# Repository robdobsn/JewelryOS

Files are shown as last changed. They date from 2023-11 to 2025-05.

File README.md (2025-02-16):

# JewelOS - Minimal OS for Jewelry

ESP32-C3 based minimal OS for Jewelry.

To build install the Raft CLI (https://github.com/robdobsn/RaftCLI)

Then run:

raft run -p <SERIALPORT>

## Devices Log

| Date | Serial | PCB Version | Notes |
|---|---|---|---|
| 2025-02-15 | 0103 | V1.5 | Seems to allow power off without any mods? BLE performance is poor. |
| 2025-02-15 | 0104 | V1.5 | Modified to remove Q4 and D5 with a wire between CHG_IN and VBAT. Turns off ok but needs power button held down to program. |

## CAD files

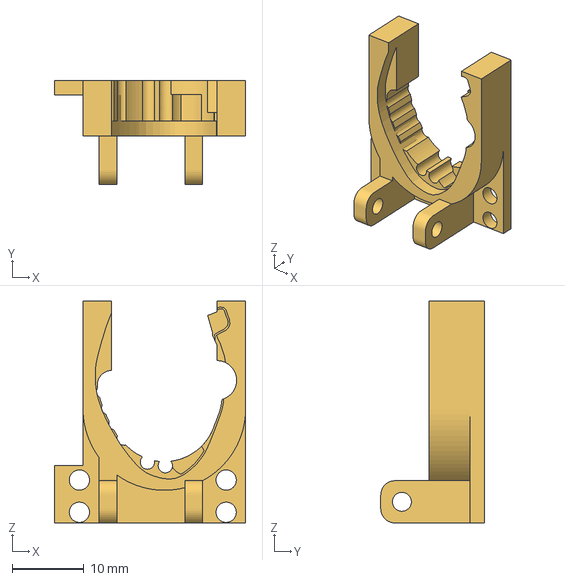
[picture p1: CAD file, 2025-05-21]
hardware/Heart Earrings/Clip1.5/Clip Base.3mf
26.7 x 14.5 x 31.0 mm

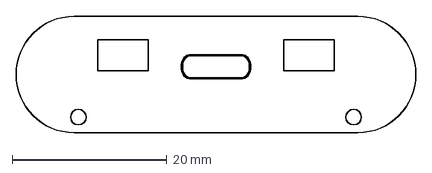
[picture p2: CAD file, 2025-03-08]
hardware/Heart Earrings/Case3.0/PCB Outline.dxf
51.6 x 15.0 mm

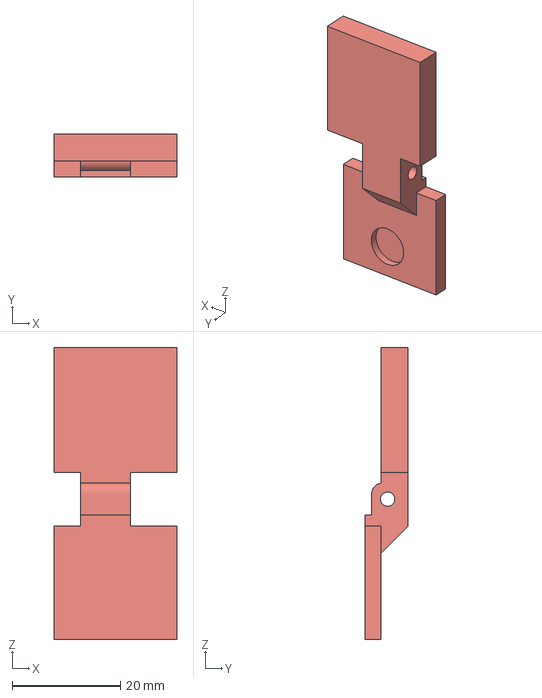
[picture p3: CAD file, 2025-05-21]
hardware/Heart Earrings/Clip1.5/Clip Plate.3mf
22.7 x 8.00 x 54.0 mm

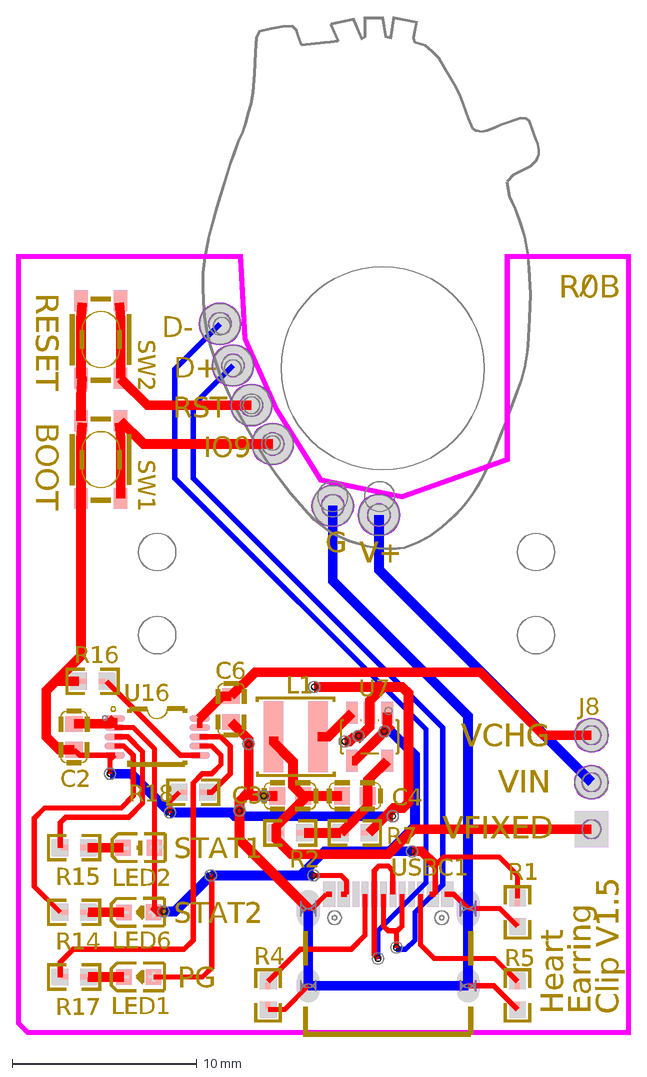
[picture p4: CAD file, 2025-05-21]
hardware/Heart Earrings/Clip1.5/PCB_Heart-Earring-1.5-Programming-Clip_2025-03-30.dxf
RESET
BOOT
STAT1
STAT2
PG
D-
D+
RST
IO9
G
V+
R0B
Heart
Earring
Clip V1.5
VFIXED
VIN
VCHG
C2
C3
C6
C4
J8
L1
LED1
LED2
LED6
R1
R14
R15
R16
R17
R18
R2
R7
R4
R5
U7
U16
USBC1
SW1
SW2

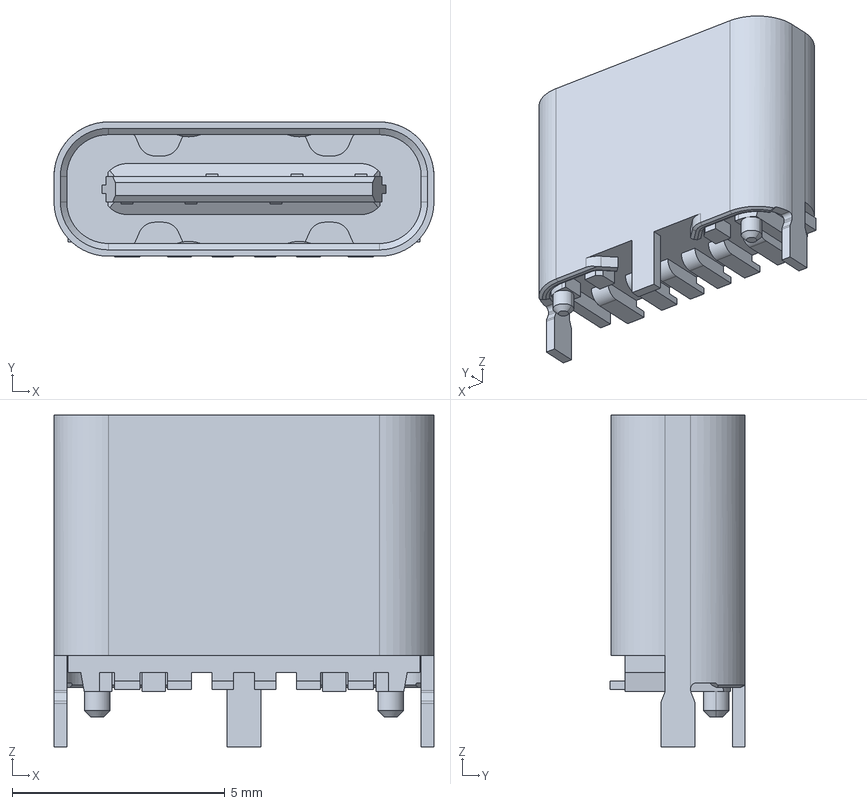
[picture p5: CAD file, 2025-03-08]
hardware/Heart Earrings/Case3.0/2480842-1.stp
8.94 x 3.18 x 7.80 mm

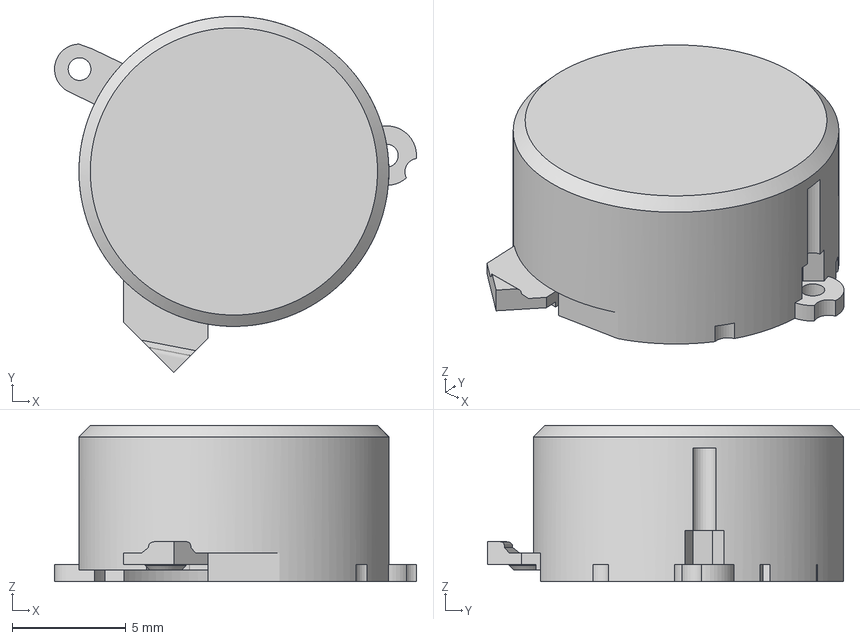
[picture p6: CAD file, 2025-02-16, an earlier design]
hardware/Heart Earrings/V1.5/Back Shell.3mf
15.9 x 15.6 x 6.85 mm

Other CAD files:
hardware/Heart Earrings/Case3.0/Earring Case V3.0 v10.f3z
hardware/Heart Earrings/V1.5/Heart Earring 1.5 v6.f3z

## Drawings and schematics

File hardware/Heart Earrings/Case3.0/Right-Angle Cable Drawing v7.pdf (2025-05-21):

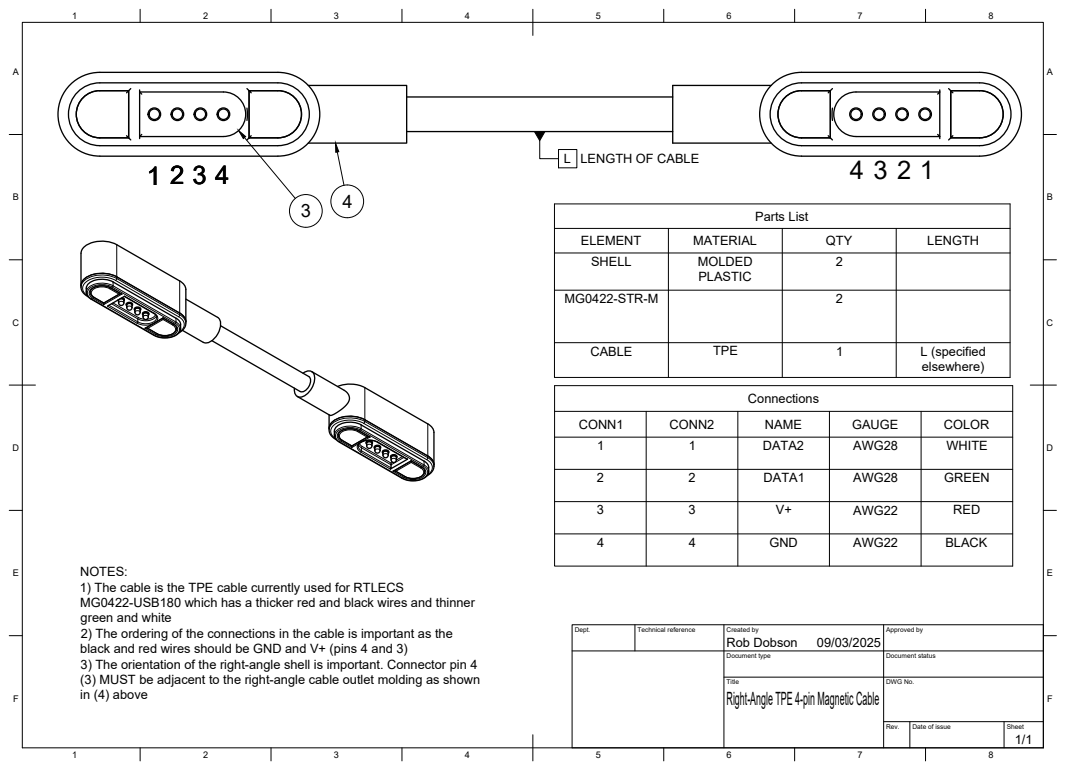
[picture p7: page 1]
Title; DWG No.; Rev.; Date of issue; Sheet; Parts List; LENGTH OF CABLE

ELEMENT | MATERIAL | QTY | LENGTH
SHELL | MOLDED PLASTIC | 2

MG0422-STR-M | | 2

CABLE | TPE | 1 | L (specified elsewhere)

CONN1 | CONN2 | NAME | GAUGE | COLOR
1 | 1 | DATA2 | AWG28 | WHITE

2 | 2 | DATA1 | AWG28 | GREEN

3 | 3 | V+ | AWG22 | RED

4 | 4 | GND | AWG22 | BLACK

NOTES:
1) The cable is the TPE cable currently used for RTLECS
MG0422-USB180 which has a thicker red and black wires and thinner
green and white
2) The ordering of the connections in the cable is important as the
black and red wires should be GND and V+ (pins 4 and 3)
3) The orientation of the right-angle shell is important. Connector pin 4
(3) MUST be adjacent to the right-angle cable outlet molding as shown
in (4) above

Dept. | Technical reference | Created by Rob Dobson 09/03/2025 | Approved by

Document type | Document status

Right-Angle TPE 4-pin Magnetic Cable

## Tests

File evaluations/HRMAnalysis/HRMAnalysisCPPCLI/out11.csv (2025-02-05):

Time (ms) | Estimated HR (Hz) | Estimated HR (bpm) | Time to next peak (ms) | Heart rate pulse interval (ms) | Red LED ADC | IR LED ADC | Filtered | ZeroCross
30380 | 1 | 60 | 666 | 1000 | 2542265 | 2829937 | 143507 | 0
30420 | 1 | 60 | 626 | 1000 | 2542241 | 2829939 | 572876 | 0
30460 | 1 | 60 | 586 | 1000 | 2542251 | 2829922 | 1.06429e+06 | 0
30500 | 1 | 60 | 546 | 1000 | 2542222 | 2829945 | 1.30295e+06 | 0
30540 | 1 | 60 | 506 | 1000 | 2542224 | 2829930 | 1.20913e+06 | 0
30580 | 1 | 60 | 466 | 1000 | 2542238 | 2829874 | 862301 | 0
30620 | 1 | 60 | 426 | 1000 | 2542199 | 2829925 | 404833 | 0
30660 | 1 | 60 | 750 | 1000 | 2542188 | 2829931 | -32917.4 | 1
30700 | 1 | 60 | 710 | 1000 | 2542170 | 2829898 | -370633 | 0
30740 | 1 | 60 | 670 | 1000 | 2542147 | 2829891 | -582824 | 0
30800 | 1 | 60 | 610 | 1000 | 2542150 | 2829830 | -683612 | 0
30840 | 1 | 60 | 570 | 1000 | 2542120 | 2829802 | -705487 | 0
30880 | 1 | 60 | 530 | 1000 | 2542086 | 2829707 | -681752 | 0
30920 | 1 | 60 | 490 | 1000 | 2542099 | 2829658 | -636758 | 0
30960 | 1 | 60 | 450 | 1000 | 2542188 | 2829647 | -583600 | 0
31000 | 1 | 60 | 410 | 1000 | 2542531 | 2829654 | -526593 | 0
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

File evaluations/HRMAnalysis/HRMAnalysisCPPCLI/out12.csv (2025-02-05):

Time (ms) | Estimated HR (Hz) | Estimated HR (bpm) | Time to next peak (ms) | Heart rate pulse interval (ms) | Red LED ADC | IR LED ADC | Filtered | ZeroCross
42770 | 1 | 60 | 276 | 1000 | 2542070 | 2827032 | 143496 | 0
42810 | 1 | 60 | 236 | 1000 | 2542069 | 2827035 | 572834 | 0
42850 | 1 | 60 | 196 | 1000 | 2542050 | 2827020 | 1.06421e+06 | 0
42890 | 1 | 60 | 156 | 1000 | 2542045 | 2827026 | 1.30285e+06 | 0
42930 | 1 | 60 | 116 | 1000 | 2542053 | 2827024 | 1.20905e+06 | 0
42990 | 1 | 60 | 56 | 1000 | 2542040 | 2827045 | 862241 | 0
43030 | 1 | 60 | 16 | 1000 | 2542038 | 2827025 | 404807 | 0
43070 | 1 | 60 | 750 | 1000 | 2542065 | 2827077 | -32907.4 | 1
43110 | 1 | 60 | 710 | 1000 | 2542039 | 2827093 | -370589 | 0
43150 | 1 | 60 | 670 | 1000 | 2542036 | 2827060 | -582755 | 0
43190 | 1 | 60 | 630 | 1000 | 2542028 | 2827052 | -683531 | 0
43230 | 1 | 60 | 590 | 1000 | 2542009 | 2826977 | -705407 | 0
43270 | 1 | 60 | 550 | 1000 | 2541972 | 2826917 | -681681 | 0
43310 | 1 | 60 | 510 | 1000 | 2541927 | 2826819 | -636704 | 0
43350 | 1 | 60 | 470 | 1000 | 2541883 | 2826721 | -583577 | 0
43410 | 1 | 60 | 410 | 1000 | 2541859 | 2826644 | -526637 | 0
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

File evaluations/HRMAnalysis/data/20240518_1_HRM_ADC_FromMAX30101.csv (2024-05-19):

Time (s) | Red | IR
1075.491 | 2816722 | 3097091
1075.531 | 2816732 | 3097118
1075.571 | 2816758 | 3097162
1075.616 | 2816795 | 3097215
1075.656 | 2816842 | 3097323
1075.696 | 2816896 | 3097397
1075.736 | 2816915 | 3097455
1075.776 | 2816966 | 3097540
1075.819 | 2816968 | 3097593
1075.859 | 2816982 | 3097617
1075.899 | 2816954 | 3097653
1075.939 | 2816926 | 3097664
1075.979 | 2816929 | 3097676
1076.019 | 2816948 | 3097718
1076.024 | 2816967 | 3097792
1076.064 | 2816984 | 3097839
1076.104 | 2816975 | 3097730
1076.144 | 2816870 | 3097348
1076.184 | 2816729 | 3096955
1076.225 | 2816702 | 3096834
1076.265 | 2816717 | 3096800
1076.305 | 2816761 | 3096835
1076.345 | 2816789 | 3096957
1076.385 | 2816832 | 3097131
1076.425 | 2816849 | 3097215
1076.465 | 2816888 | 3097249
1076.505 | 2816898 | 3097273
1076.545 | 2816926 | 3097340
1076.585 | 2816942 | 3097425
1076.625 | 2816915 | 3097466
1076.665 | 2816965 | 3097555
1076.705 | 2816991 | 3097590
1076.745 | 2816972 | 3097622
1076.785 | 2816939 | 3097632
1076.829 | 2816943 | 3097672
1076.869 | 2816969 | 3097708
1076.909 | 2816957 | 3097703
1076.949 | 2816921 | 3097687
1076.989 | 2816966 | 3097751
1077.034 | 2817063 | 3097865
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

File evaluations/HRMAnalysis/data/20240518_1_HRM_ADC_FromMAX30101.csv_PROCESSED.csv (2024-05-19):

Time (ms) | Estimated HR (Hz) | Estimated HR (bpm) | Time to next peak (ms) | Heart rate pulse interval (ms) | Red LED ADC | IR LED ADC
0 | 1 | 60 | 750 | 1000 | 2.81672e+06 | 3.09709e+06
40 | 1 | 60 | 710 | 1000 | 2.81673e+06 | 3.09712e+06
80 | 1 | 60 | 670 | 1000 | 2.81676e+06 | 3.09716e+06
125 | 1 | 60 | 625 | 1000 | 2.8168e+06 | 3.09722e+06
165 | 1 | 60 | 585 | 1000 | 2.81684e+06 | 3.09732e+06
205 | 1 | 60 | 545 | 1000 | 2.8169e+06 | 3.0974e+06
245 | 1 | 60 | 505 | 1000 | 2.81692e+06 | 3.09746e+06
285 | 1 | 60 | 465 | 1000 | 2.81697e+06 | 3.09754e+06
328 | 1 | 60 | 422 | 1000 | 2.81697e+06 | 3.09759e+06
368 | 1 | 60 | 382 | 1000 | 2.81698e+06 | 3.09762e+06
408 | 1 | 60 | 342 | 1000 | 2.81695e+06 | 3.09765e+06
448 | 1 | 60 | 302 | 1000 | 2.81693e+06 | 3.09766e+06
488 | 1 | 60 | 262 | 1000 | 2.81693e+06 | 3.09768e+06
528 | 1 | 60 | 222 | 1000 | 2.81695e+06 | 3.09772e+06
533 | 1 | 60 | 217 | 1000 | 2.81697e+06 | 3.09779e+06
573 | 1 | 60 | 177 | 1000 | 2.81698e+06 | 3.09784e+06
613 | 1 | 60 | 137 | 1000 | 2.81698e+06 | 3.09773e+06
653 | 1 | 60 | 97 | 1000 | 2.81687e+06 | 3.09735e+06
693 | 1 | 60 | 57 | 1000 | 2.81673e+06 | 3.09696e+06
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

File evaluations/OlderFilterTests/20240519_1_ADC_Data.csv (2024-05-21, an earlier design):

Time (s) | Red | IR
17.496 | 2807554 | 3092343
17.536 | 2807555 | 3092362
17.576 | 2807574 | 3092398
17.616 | 2807595 | 3092452
17.656 | 2807625 | 3092495
17.7 | 2807632 | 3092558
17.74 | 2807653 | 3092599
17.78 | 2807659 | 3092654
17.82 | 2807676 | 3092702
17.86 | 2807682 | 3092738
17.902 | 2807695 | 3092792
17.942 | 2807699 | 3092845
17.982 | 2807726 | 3092899
18.022 | 2807753 | 3092968
18.062 | 2807755 | 3093022
18.104 | 2807761 | 3093064
18.144 | 2807690 | 3092863
18.184 | 2807573 | 3092567
18.224 | 2807528 | 3092404
18.264 | 2807509 | 3092378
18.304 | 2807516 | 3092373
18.344 | 2807521 | 3092420
18.384 | 2807535 | 3092505
18.424 | 2807555 | 3092575
18.464 | 2807565 | 3092615
18.506 | 2807558 | 3092635
18.546 | 2807567 | 3092681
18.586 | 2807588 | 3092774
18.626 | 2807602 | 3092855
18.666 | 2807612 | 3092917
18.709 | 2807643 | 3093021
18.749 | 2807652 | 3093083
18.789 | 2807672 | 3093176
18.829 | 2807703 | 3093253
18.869 | 2807717 | 3093310
18.914 | 2807727 | 3093365
18.954 | 2807751 | 3093429
18.994 | 2807769 | 3093476
19.034 | 2807762 | 3093505
19.074 | 2807714 | 3093349
19.115 | 2807570 | 3092981
19.155 | 2807470 | 3092727
19.195 | 2807446 | 3092646
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

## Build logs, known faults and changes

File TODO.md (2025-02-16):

2025/02/15 State of Play

Manufactured V1.5 have two issues:
[] The battery is connected via a P-CH FET which is always on and this means that the power-down circuitry is always on and the battery will be drained. The solution applied in V1.8 schematic is to change the FET to a schottky diode but this may affect charging a little?
[] The selection of pin 8 for driving LEDS3 causes that pin to be pulled low at boot. This isn't an issue normally but pin 8 is a strapping pin and must be pulled high to program. This doesn't seem to stop all devices from being programmed - just some of them - and the pin can be pulled high manually to program the device. The solution applied in V1.8 is to move the LEDS3 to pin 10 and SDA to pin 8.

A bodge for the first issue is to remove diode D5. This means that the power-down circuitry works when on battery but the power button needs to be held down when programming otherwise the device will power down. This is an ok solution for the moment.

In addition in V1.8 the layout has been changed to:
[] create more space around the battery for the shell mounting points
[] improve the RF path for the antenna
[] increase the width of power traces
[] 4 layer PCB

Further hardware work:
[] Still need to resolve the way charging is done in the case - there is very little exposed metal to work with and most battery slide connectors are too big to work - was considering pogo pin connectors with very short throw and a way to introduce the earring on a slope so that it pushes up against the connector rather than going sideways against it
[] Change the sensor to a BGA type which would fit flatter to the ear
[] Consider whether having the antenna touching the ear in some cases matters

Further firmware work:
[] The evaluations|HRMAnalsis|DebugCPPAnalysis folder is intended to compare the output of the hrm algorithms run on the device with the equivalent algorithms run on the PC - it seems to match in performance generally but I think some parameters may differ now - these should be back-ported to the CPP code
[] Collection of raw samples over bluetooth using publishing works well but the samples only include the raw values - it would be good to get at the processed (filter, zero crossing, PLL, etc) parameters if possible - maybe add a device to do this and publish from that
[] The code still includes the older work using a local I2C bus and MAX30101 drivers - this can be removed
[] Investigation of reduced LED intensity or switching to IR only (is this possible) might be worth considering to save battery and reduce glow on earlobe
[] A slow version of the animated LEDs routine might be good for video creation

Older notes:
[] Clear LED pixels on power down
[] BLE connect should stop power saving mode
[] BLE disconnect after timeout and force reconnect
[] get grid message from app
[] allow message colour to be set - inc random colours
[] LED patterns through app
[] microphone
[] log heart rate
[] transfer log data over BLE
[] fix problem with LED strip transaction complete check - seems it doesn't work as on grid earrings when going to sleep after waiting for completion the pixels can get corrupted - maybe just not calling the function at all ? - there is a delay currenting inserted to solve this - look for TODO
[] fix any other TODOs
[] main processor clock rate is not set low

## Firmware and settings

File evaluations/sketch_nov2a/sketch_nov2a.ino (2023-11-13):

static const int HRINT = 0;
static const int LEDS_1 = 5;
static const int LEDS_2 = 3;
static const int LEDS_3 = 1;
static const int LEDS_4 = 6;
static const int I2C_SCL = 8;
static const int I2C_SDA = 10;
static const int PWR_OFF = 7;

#include <Wire.h>
#include "MAX30105.h"
#include "heartRate.h"
#include "esp_clk.h"

#define SETUP_HRM
#define DIABLE_HRM_IR
// #define GET_HRM_READINGS
// #define LOG_HRM_READINGS
// #define SERIAL_OUTPUT_CLOCK_SPEED
#define TEST_LIGHT_SLEEP_NO_LEDS
// #define TEST_LEDS_ALONE_IN_SLEEP
// #define USE_LED_PWM
// #define SLEEP_LIGHT

#define PWM_VALUE_FOR_ON 20

MAX30105 hrmSensor;
TwoWire i2cOne = TwoWire(0);
const byte RATE_SIZE = 4; //Increase this for more averaging. 4 is good.
byte rates[RATE_SIZE]; //Array of heart rates
byte rateSpot = 0;
long lastBeat = 0; //Time at which the last beat occurred

float beatsPerMinute = 60;
int beatAvg = 60;
int ledsBPM = 60;
uint32_t prevLedPos = 0;
uint32_t cyclePos = 0;
const uint32_t LED_MAX = 4;
const uint32_t CYCLE_MAX = 5;
uint32_t cycleLastMs = 0;
uint32_t cycleStateTimeMs = 250;
const uint32_t LED_PULSE_SLEEP_US = 30000;
const uint32_t IDLE_SLEEP_US = 970000;

static const int cyclePosLeds[] = {LEDS_4, LEDS_3, LEDS_2, LEDS_1}; 

uint32_t calcLEDSHoldTimeMs(float bpm)
{
  return 60000.0 / bpm / CYCLE_MAX;
}

void servicePulseOut()
{
  if (cycleLastMs == 0)
  {
    cycleStateTimeMs = calcLEDSHoldTimeMs(ledsBPM);
    cyclePos = 0;
    cycleLastMs = millis();
  }

  if (millis() > cycleLastMs + cycleStateTimeMs)
  {
#ifdef USE_LED_PWM
    analogWrite(cyclePosLeds[(cyclePos+CYCLE_MAX-1)%CYCLE_MAX], 0);
    analogWrite(cyclePosLeds[cyclePos], PWM_VALUE_FOR_ON);
#else
    if (cyclePos < LED_MAX)
    {
      digitalWrite(cyclePosLeds[prevLedPos], 0);
      digitalWrite(cyclePosLeds[cyclePos], 1);
      prevLedPos = cyclePos;
    }
    else
    {
      digitalWrite(cyclePosLeds[prevLedPos], 0);
    }
#endif
    cycleLastMs = millis();
    cyclePos = (cyclePos + 1) % CYCLE_MAX;
    if (cyclePos == 0)
    {
          cycleStateTimeMs = calcLEDSHoldTimeMs(ledsBPM);
    }
  }

}

void setup() {
#ifdef SERIAL_OUTPUT_CLOCK_SPEED
  Serial.begin(115200);
  uint32_t cpu_freq = esp_clk_cpu_freq();
  Serial.print("CPU Frequency: ");
  Serial.println(cpu_freq);
#endif

  setCpuFrequencyMhz(10);

#ifdef SERIAL_OUTPUT_CLOCK_SPEED
  cpu_freq = esp_clk_cpu_freq();
  Serial.print("CPU Frequency: ");
  Serial.println(cpu_freq);
#endif


  // pinMode(EXT_VDD, OUTPUT);
  // digitalWrite(EXT_VDD, HIGH);

  pinMode(LEDS_1, OUTPUT);
  pinMode(LEDS_2, OUTPUT);
  pinMode(LEDS_3, OUTPUT);
  pinMode(LEDS_4, OUTPUT);
#ifdef USE_LED_PWM
  analogWrite(LEDS_1, 0);
  analogWrite(LEDS_2, 0);
  analogWrite(LEDS_3, 0);
  analogWrite(LEDS_4, 0);
#else
  digitalWrite(LEDS_1, 0);
  digitalWrite(LEDS_2, 0);
  digitalWrite(LEDS_3, 0);
  digitalWrite(LEDS_4, 0);
#endif

#ifdef SETUP_HRM
  delay(100);
  i2cOne.begin(I2C_SDA, I2C_SCL, 100000);

    // Initialize sensor
  if (hrmSensor.begin(i2cOne) == false)
  {
    Serial.println("MAX30105 was not found. Please check wiring/power. ");
    while (1);
  }

  //Setup to sense a nice looking saw tooth on the plotter
  byte ledBrightness = 0x1F; //Options: 0=Off to 255=50mA
  byte sampleAverage = 8; //Options: 1, 2, 4, 8, 16, 32
  byte ledMode = 3; //Options: 1 = Red only, 2 = Red + IR, 3 = Red + IR + Green
  int sampleRate = 100; //Options: 50, 100, 200, 400, 800, 1000, 1600, 3200
  int pulseWidth = 411; //Options: 69, 118, 215, 411
  int adcRange = 4096; //Options: 2048, 4096, 8192, 16384

  // hrmSensor.setup(ledBrightness, sampleAverage, ledMode, sampleRate, pulseWidth, adcRange); //Configure sensor with these settings

  hrmSensor.setup(0, 4, 1, 50, 411, 4096); //Configure sensor with default settings
  hrmSensor.setPulseAmplitudeRed(0); //Turn Red LED to low to indicate sensor is running
  hrmSensor.setPulseAmplitudeGreen(0); //Turn off Green LED

#ifdef DIABLE_HRM_IR
  hrmSensor.setPulseAmplitudeIR(0);
#endif
#endif
}

uint32_t debugLastMs = 0;

void loop()
{

#ifdef GET_HRM_READINGS

  long irValue = 0;
  // for (int loopIdx = 0; loopIdx < 500; loopIdx++)
  // {
    // Serial.println(hrmSensor.getIR()); //Send raw data to plotter
    irValue = hrmSensor.getIR();

    if (checkForBeat(irValue) == true)
    {
      //We sensed a beat!
      long delta = millis() - lastBeat;
      lastBeat = millis();

      beatsPerMinute = 60 / (delta / 1000.0);

      if (beatsPerMinute < 255 && beatsPerMinute > 20)
      {
        rates[rateSpot++] = (byte)beatsPerMinute; //Store this reading in the array
        rateSpot %= RATE_SIZE; //Wrap variable

        //Take average of readings
        beatAvg = 0;
        for (byte x = 0 ; x < RATE_SIZE ; x++)
          beatAvg += rates[x];
        beatAvg /= RATE_SIZE;
      }
    }

  //   delay(10);
  // }

#ifdef LOG_HRM_READINGS
  if (millis() > debugLastMs + 250)
  {
    Serial.print("IR=");
    Serial.print(irValue);
    Serial.print(", BPM=");
    Serial.print(beatsPerMinute);
    Serial.print(", AvgBPM=");
    Serial.print(beatAvg);

    // if (irValue < 50000)
    //   Serial.print(" No finger?");

    Serial.println();
#endif
    debugLastMs = millis();
  }

#endif


  // esp_sleep_enable_timer_wakeup(1000000);
  // gpio_hold_en((gpio_num_t)EXT_VDD);
  // esp_light_sleep_start();
  // gpio_hold_en((gpio_num_t)EXT_VDD);

  // esp_sleep_enable_timer_wakeup(20000);
  // gpio_hold_en((gpio_num_t)LEDS_1);
  // esp_light_sleep_start();
  // digitalWrite(LEDS_1, HIGH);
  // esp_deep_sleep_start();

#ifdef SERVICE_PULSE_OUT
  servicePulseOut();
#endif

#ifdef SLEEP_LIGHT
  esp_sleep_enable_timer_wakeup(cyclePos < LED_MAX ? LED_PULSE_SLEEP_US : IDLE_SLEEP_US);
  esp_light_sleep_start();
#elif defined(TEST_LIGHT_SLEEP_NO_LEDS)
  esp_sleep_disable_wakeup_source(ESP_SLEEP_WAKEUP_ALL);
  esp_light_sleep_start();
#endif
}

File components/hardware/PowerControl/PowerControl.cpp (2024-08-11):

/////////////////////////////////////////////////////////////////////////////////////////////////////////////////
//
// Power control
//
// Rob Dobson 2023
//
/////////////////////////////////////////////////////////////////////////////////////////////////////////////////

#include "PowerControl.h"
#include "RaftJsonIF.h"
#include "ConfigPinMap.h"
#include "RaftUtils.h"
#include "esp_sleep.h"

// #define DEBUG_USER_BUTTON_PRESS
// #define DEBUG_POWER_CONTROL

static const char *MODULE_PREFIX = "PowerControl";

PowerControl::PowerControl()
{
}

PowerControl::~PowerControl()
{
}

void PowerControl::setup(RaftJsonIF& config)
{
    // Get power control pin
    String pinName = config.getString("powerCtrlPin", "");
    _powerCtrlPin = ConfigPinMap::getPinFromName(pinName.c_str());

    // Set power control pin to ensure power remains on
    if (_powerCtrlPin >= 0)
    {
        // Set power control pin
        pinMode(_powerCtrlPin, OUTPUT);
        digitalWrite(_powerCtrlPin, HIGH);
    }

    // Setup VSENSE pin
    pinName = config.getString("vsensePin", "");
    _vsensePin = ConfigPinMap::getPinFromName(pinName.c_str());
    if (_vsensePin >= 0)
    {
        // Set VSENSE pin
        pinMode(_vsensePin, INPUT);
    }

    // Get battery low voltage
    _batteryLowV = config.getDouble("batteryLowV", BATTERY_LOW_V_DEFAULT);

    // Get VSENSE button level
    _vsenseButtonLevel = config.getLong("vsenseButtonLevel", VSENSE_BUTTON_LEVEL_DEFAULT);

    // Get button off time
    _buttonOffTimeMs = config.getLong("buttonOffTimeMs", 2000);

    // Get ADC calibration
    _vsenseSlope = VSENSE_SLOPE_DEFAULT;
    _vsenseIntercept = VSENSE_INTERCEPT_DEFAULT;
    double v1 = config.getDouble("adcCalib/v1", 0);
    int a1 = config.getLong("adcCalib/a1", 0);
    double v2 = config.getDouble("adcCalib/v2", 0);
    int a2 = config.getLong("adcCalib/a2", 0);
    LOG_I(MODULE_PREFIX, "setup powerCtrlPin %d vSensePin %d v1 %.2f a1 %d v2 %.2f a2 %d", 
                _powerCtrlPin, _vsensePin, v1, a1, v2, a2);

    // If a1 and a2 specified then use them
    if ((a1 > 0) && (a2 > 0))
    {
        _vsenseSlope = (v2 - v1) / (a2 - a1);
        _vsenseIntercept = v1 - _vsenseSlope * a1;
    }

    // Debug
    if (_vsensePin > 0)
    {
        uint32_t adcReading = _vsensePin > 0 ? analogRead(_vsensePin) : 0;
        LOG_I(MODULE_PREFIX, "setup powerCtrlPin %d vSensePin %d currentADC %d currentVoltage %.2fV vsenseSlope %.5f vsenseIntercept %.2f batteryLowV %.2f vSenseButtonLevel %d buttonOffTime %dms", 
                    _powerCtrlPin, _vsensePin, (int)adcReading, 
                    getVoltageFromADCReading(adcReading), 
                    _vsenseSlope, _vsenseIntercept,
                    _batteryLowV, _vsenseButtonLevel, _buttonOffTimeMs);
    }
    else
    {
        LOG_I(MODULE_PREFIX, "setup FAILED powerCtrlPin %d vSensePin INVALID vsenseSlope %.5f vsenseIntercept %.2f", 
                    _powerCtrlPin, _vsenseSlope, _vsenseIntercept);
    }

}

void PowerControl::loop()
{
    // Update VSENSE average
    if (_vsensePin < 0)
        return;

    // Get VSENSE value
    uint32_t vsenseVal = analogRead(_vsensePin);

    // The pushbutton is wired to VSENSE so if it is pressed the VSENSE pin
    // will go above a threshold
    if (vsenseVal > _vsenseButtonLevel)
    {
        // Note time press started
        if (!_buttonPressed)
            _buttonPressDownTimeMs = millis();

        // Pressed
        _buttonPressed = true;
        _buttonPressChangeTimeMs = millis();

        // Check if button press is over the off time threshold
        if (Raft::timeElapsed(millis(), _buttonPressDownTimeMs) > _buttonOffTimeMs)
        {
            // Debug
#ifdef DEBUG_USER_BUTTON_PRESS
            if (Raft::isTimeout(millis(), _lastWarnUserShutdownTimeMs, 1000))
            {
                LOG_I(MODULE_PREFIX, "loop button pressed for %dms (vsense %d buttonLevel %d buttonOffTime %dms)",
                    (int)Raft::timeElapsed(millis(), _buttonPressDownTimeMs), vsenseVal, _vsenseButtonLevel, _buttonOffTimeMs);
                _lastWarnUserShutdownTimeMs = millis();
            }
#endif // DEBUG_USER_BUTTON_PRESS

            // Shutdown initiated
#ifdef FEATURE_POWER_CONTROL_USER_SHUTDOWN
            _shutdownInitiated = true;
#endif // FEATURE_POWER_CONTROL_USER_SHUTDOWN
        }
    }
    else
    {
        // Not pressed - debounce
        if (_buttonPressed)
        {
            if (Raft::isTimeout(millis(), _buttonPressChangeTimeMs, 200))
            {
                // Button pressed
#ifdef DEBUG_USER_BUTTON_PRESS
                LOG_I(MODULE_PREFIX, "loop button pressed for %dms and released (button off time %dms)",
                        (int)Raft::timeElapsed(millis(), _buttonPressDownTimeMs), _buttonOffTimeMs);
#endif // DEBUG_USER_BUTTON_PRESS
                _buttonPressed = false;
            }
        }
        else
        {
            // Average vsense values that are not button presses
            _vsenseAvg.sample(vsenseVal);
            _sampleCount++;
        }
    }

    // Debug
#ifdef DEBUG_POWER_CONTROL
    if (Raft::isTimeout(millis(), _lastDebugTimeMs, 1000))
    {
        LOG_I(MODULE_PREFIX, "loop vSense %d avgVSense %d Vcalculated %.2fV battLowThreshold %.2fV sampleCount %d buttonLevel %d",
                    analogRead(_vsensePin), 
                    _vsenseAvg.getAverage(),
                    getVoltageFromADCReading(_vsenseAvg.getAverage()),
                    _batteryLowV,
                    _sampleCount,
                    _vsenseButtonLevel);
        _lastDebugTimeMs = millis();
    }
#endif // DEBUG_POWER_CONTROL

    // Check for shutdown due to battery low
    if (!_shutdownInitiated && (_sampleCount > 100))
    {
        // Get voltage
        float voltage = getVoltageFromADCReading(_vsenseAvg.getAverage());

        // Check for shutdown
        if (voltage < _batteryLowV)
        {
            // Debug
#ifdef DEBUG_POWER_CONTROL
            if (Raft::isTimeout(millis(), _lastWarnBatLowShutdownTimeMs, 1000))
            {
                LOG_I(MODULE_PREFIX, "Battery low %s voltage %.2fV instADC %d avgADC %d battLowThreshold %.2fV", 
#ifdef FEATURE_POWER_CONTROL_LOW_BATTERY_SHUTDOWN
                        "shutting down",
#else
                        "!!! SHUTDOWN DISABLED !!!",
#endif // FEATURE_POWER_CONTROL_LOW_BATTERY_SHUTDOWN
                    voltage, analogRead(_vsensePin), _vsenseAvg.getAverage(), _batteryLowV);
                _lastWarnBatLowShutdownTimeMs = millis();
            }
#endif // DEBUG_POWER_CONTROL

            // Shutdown initiated
#ifdef FEATURE_POWER_CONTROL_LOW_BATTERY_SHUTDOWN
            _shutdownInitiated = true;
#endif // FEATURE_POWER_CONTROL_LOW_BATTERY_SHUTDOWN
        }
    }
}
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

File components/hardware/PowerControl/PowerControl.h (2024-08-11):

/////////////////////////////////////////////////////////////////////////////////////////////////////////////////
//
// Power control
//
// Rob Dobson 2023
//
/////////////////////////////////////////////////////////////////////////////////////////////////////////////////

#pragma once

#include <stdint.h>
#include <SimpleMovingAverage.h>

class RaftJsonIF;

class PowerControl
{
public:
    PowerControl();
    virtual ~PowerControl();

    // Setup
    void setup(RaftJsonIF& config);

    // Service
    void loop();

    // Get voltage
    float getVoltageFromADCReading(uint32_t adcReading);

    // Check if shutdown initiated
    bool isShutdownRequested()
    {
        return _shutdownInitiated;
    }

    // Handle shutdown
    void shutdown();

private:

    // VSENSE threshold when button is pressed
    static const uint32_t VSENSE_BUTTON_LEVEL_DEFAULT = 2300;
    uint32_t _vsenseButtonLevel = VSENSE_BUTTON_LEVEL_DEFAULT;

    // VSENSE to voltage conversion for Heart Earrings
    // Note that this is overridden by values in the sysTypes if present
    // Measurements from multimeter
    // 3.584V = 1600
    // 3.697V = 1659
    // 3.804V = 1704
    // 3.899V = 1748
    // 4.003V = 1790
    // 4.107V = 1845
    // 4.203V = 1887
    // Using excel to fit a curve with 0 intercept ...
    static constexpr float VSENSE_SLOPE_DEFAULT = 0.00223;
    static constexpr float VSENSE_INTERCEPT_DEFAULT = 0.0;
    double _vsenseSlope = VSENSE_SLOPE_DEFAULT;
    double _vsenseIntercept = VSENSE_INTERCEPT_DEFAULT;

    // Shutdown due to battery low threshold
    static constexpr float BATTERY_LOW_V_DEFAULT = 3.55;
    float _batteryLowV = BATTERY_LOW_V_DEFAULT;

    // Shutdown initiated
    bool _shutdownInitiated = false;
    
    // Power control pin
    int _powerCtrlPin = -1;

    // Time to hold power control pin low for shutdown
    static constexpr uint32_t TIME_TO_HOLD_POWER_CTRL_PIN_LOW_MS = 500;

    // VSENSE pin
    int _vsensePin = -1;

    // VSENSE averaging
    SimpleMovingAverage<100> _vsenseAvg;
    uint32_t _sampleCount = 0;

    // Debounce button
    bool _buttonPressed = false;
    uint32_t _buttonPressChangeTimeMs = 0;
    uint32_t _buttonPressDownTimeMs = 0;

    // Off time threshold for button press ms
    static constexpr uint32_t BUTTON_OFF_TIME_MS_DEFAULT = 2000;
    uint32_t _buttonOffTimeMs = BUTTON_OFF_TIME_MS_DEFAULT;

    // Debug
    uint32_t _lastDebugTimeMs = 0;
    uint32_t _lastWarnBatLowShutdownTimeMs = 0;
    uint32_t _lastWarnUserShutdownTimeMs = 0;
};

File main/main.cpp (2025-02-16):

/////////////////////////////////////////////////////////////////////////////////////////////////////////////////
//
// Main entry point
//
// JewelOS
// Rob Dobson 2024
//
/////////////////////////////////////////////////////////////////////////////////////////////////////////////////

#include "RaftCoreApp.h"
#include "RegisterSysMods.h"
#include "BusI2C.h"
#include "Jewelry.h"

/// @brief Main entry point for application
extern "C" void app_main(void)
{
    RaftCoreApp raftCoreApp;

    // Register SysMods from RaftSysMods library
    RegisterSysMods::registerSysMods(raftCoreApp.getSysManager());

    // Register BusI2C
#ifdef FEATURE_REGISTER_I2C_BUS_IN_MAIN
    raftBusSystem.registerBus("I2C", BusI2C::createFn);
#endif

    // Jewelry
    raftCoreApp.registerSysMod("Jewelry", Jewelry::create, true);

    // Loop forever
    while (1)
    {
        // Service the app
        raftCoreApp.loop();
    }
}

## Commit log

2023-11-24 Added LEDGrid and hardware detection
2023-12-11 Added BLE functionality
    Added LEDGrid
2023-12-13 LED pattern improvements
2023-12-13 Fixed order of pixels
    [LEDGrid.cpp, LEDGrid.h, LEDPatternScrollMsg.h]
2023-12-21 VSense adc calibration now in SysTypes
    Changed default LEDGrid message
2024-01-26 Changed buildConfigs to systypes folder
    [partitions.csv]
2024-05-19 Updated for latest version of Raft
    [partitions.csv]
2024-05-19 Work on algorithm analysis
    [20240518_1_HRM_ADC_FromMAX30101.csv, 20240518_1_HRM_ADC_FromMAX30101.csv_PROCESSED.csv, 20240518_2_HRM_ADC_FromMAX30101.csv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]
2024-05-21 Work on ZC+PLL algorithm for Heart-Rate detection
    [20240519_1_ADC_Data.csv, 20240519_1_ADC_Data.csv_PROCESSED.csv, 20240519_1_HRM_Data.csv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]
2024-06-03 Captured test data update
    [20240521_2_ADC_Data.csv]
2024-08-11 Added gpio_hold_dis() and gpio_hold_en() Reduced pulse duration to 250ms Added settings for batteryLow, vsenseButtonLevel and buttonOffTime Removed (temporarily) the detect hardware function
    [partitions.csv]
2024-08-12 Moved heart earring sleep code to main sysmod Moved HRM sample collection to config
2024-10-31 Moving to updated Raft libs
    Disabled LED Pixel code for now with a FEATURE
    Using branched RaftCore, RaftI2C and RaftSysMods for now
    Removed hardware detection
    Added folder for PCB designs
2024-11-02 Added heart rate report via BLE std service
    [20241031 HRM data 1st 160 rows.csv, 20241031 HRM data 1st 160 rows.csv_PROCESSED.csv, 20241031 HRM data 76 - 120 - 89 - P2.csv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]
2024-11-26 Added new SysType for Heart v1.5
    [partitions.csv]
2025-02-04 Improved collection of HRM data Tidied up PLL code Added debug analysis jupyter notebook Log processing of sample collected data Fixed for devtype info change in RaftCore
    [HRMAnalysis.h, Jewelry.cpp, PhaseLockedLoop.h]
2025-02-07 Working on improving PLL performance
    [20241031 HRM data 76 - 120 - 89.csv_PROCESSED.csv, 20241101 HTM data short.csv_PROCESSED.csv, 20250205-141843_log.csv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]
2025-02-13 Added export of MagServo4 design files from EasyEDA
    [Heart-Earrings_2025-02-13.schdoc, PCB_Heart-Earrings-1.7_2025-02-13.pcbdoc]
2025-02-14 Updated PCB and shell files
    [Back Shell.3mf, Heart Earring 1.5 v6.f3z, Heart-Earrings_2025-02-14.schdoc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]
2025-02-16 More work on PLL
    [20250214-1533-bench.tsv, 20250214-1533-bench_log.csv, 20250214-1533-bench_processed.csv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]
2025-03-08 Updated case design V3
    [2480842-1.stp, Earring Case V3.0 v10.f3z, PCB Outline.dxf]
2025-05-21 Drawings, etc
    [Clip Base.3mf, Clip Plate.3mf, PCB_Heart-Earring-1.5-Programming-Clip_2025-03-30.dxf]
